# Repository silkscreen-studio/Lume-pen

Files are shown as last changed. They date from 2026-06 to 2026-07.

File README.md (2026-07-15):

# LUME Pen
The most ordinary pen, except that it has electronics stuffed inside, on a flexible PCB. It can even tell the time and double as a pomodoro timer, thanks to a tiny custom 7 segment display, with a capacitive slider to control it easily 

I mainly made this project to challenge myself on integrating electronics in such a tight space (6mm hollow tube) and to design my first Flex PCB. Also, I always thought that integrating a mini segmented display and a capacitive slider into a pen body would look really cool, and it looks exactly as cool as I imagined it. 

With this clock and pomodoro timer included in the tool everyone uses when working or studying, no need for distracting apps and constant checks on a phone!

<br><br>
LUME Pen ZINE V1 1

The Lume Pen body is split in 3 parts, in MJF Nylon and SLA clear resin, to make assembly possible while giving texture to the design.
The flex PCB, made of multiple flaps bent over each other to achieve the 5mm width runs all along the pen body, while keeping space for an half-long BIC® cartridge as well as a rod shaped 4.5mm wide li-ion battery. The segments on the display are shaped from the 30x 0402 LEDs with 3 layers: a small 3D printed spacer (FDM, .2mm nozzle), a thin diffuser sheet and a custom designed light mask to get sharp segments, made from a  precisely laser cut 100 microns thin steel plate, also known as a stencil...

# Product Key features:
 - The Lume pen can tell the time, be used as a Pomodoro timer (configurable timer with multiple sessions possible, alterning 5-60 min of work with a 5 minute break), and... be used as a normal pen too...
 - Sleek design, MJF Nylon & Clear Resin body to see the electronics
 - Capacitive slider to enable gesture control
 - Stylish Segmented Display Font [^1], made from 30 orange LEDs
 - No ON/OFF switch: capacitive CMD button to shut it down, can last a few months on a single charge when turned off
 - Magnetic charger (with pogopins), to charge it easily (from a USB-A port)

# Technical Key features:
## Lume pen:
 - Built around the power efficient `ATtiny1616` MCU (16kB FLASH, 2kB SRAM)
 - 2x I²C ICs for the RTC (`RX8111`) and capacitive touch management (`AW93105`)
 - Onboard `LP5907` 3.0V LDO with low quiscent current (12µA)
 - 3.7V Li-ion rod shaped battery, 25mAh, and its `BQ25170` charging IC
 - interfaces with the charger thanks to 4 gold plated contacts (pogopins on the charger): VIN, GND, UPDI and a mating detect pin.
 - Charlieplexed 30x 0402 orange LEDs 4 digit 7-segment display
 - Flexible PCB, ENIG, with stiffener: 125x40mm² panel with both the LUME and charger PCB
## Magnetic charger:
 - Smart charger with the $0.25 `CH32V003` MCU (16kB FLASH, 2kB SRAM)
 - Load switch (`TPS2553DRVR-1`) with latch off overcurrent and short circuit protection, MCU FAULT assertion, MCU ENABLE,
 - mating detection to enable/disable charging
 - 5 white LEDs to display charging animation, and 1 RED FAULT LED

# Schematic:
## Lume Pen schematic
LUME_pen_schematic_V1 0

## Charger shematic

LUME_pen_charger_schematic_V1 0

# PCB Layout:
## LUME flexible Panel:
I decided to panelize it with 2 Lume variant, where I have a line pattern silkscreen on one variant, and a full white pour on the other one, on all the visible parts. Not knowing what the yellow coverlay would look like in real life, I could now see which one looks better. Ordering this dual panel is only $6 more expensive ($40.42 for 5 panel, so 10 Lume PCBs) than the single panel ($34.14 for 5 panel, so 5 Lume PCBs). Why not directly choose a white (or black) coverlay? As it adds a $8 fee, it would have been $42.14 for the single panel (5 Lume PCBs).

For $40, I have 10 Lume pen PCBs (5 of each variant), with PI stiffener and ENIG finish.

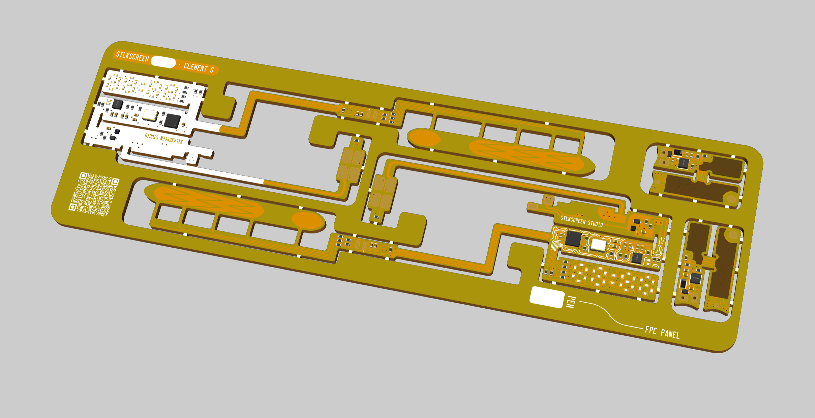
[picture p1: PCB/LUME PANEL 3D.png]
LUME PANEL 3D

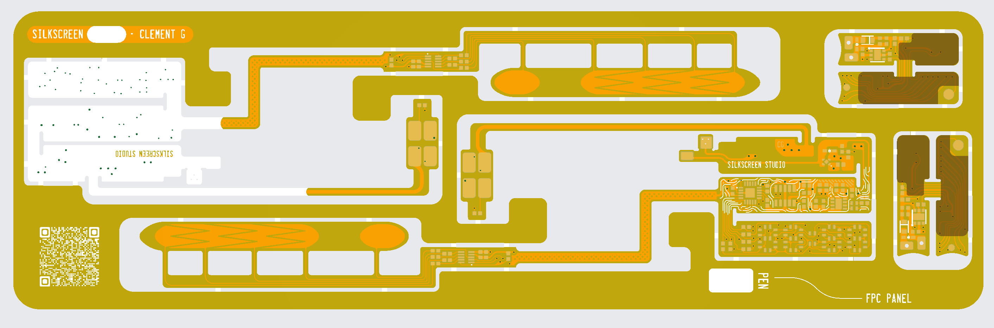
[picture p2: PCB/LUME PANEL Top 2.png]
LUME PANEL Top 2

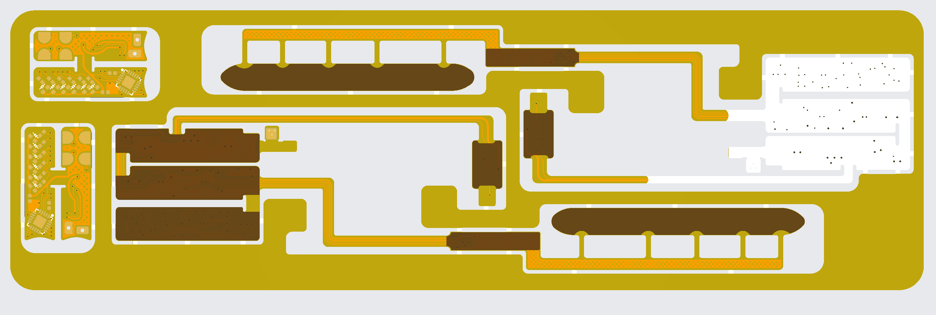
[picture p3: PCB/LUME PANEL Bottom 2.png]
LUME PANEL Bottom 2


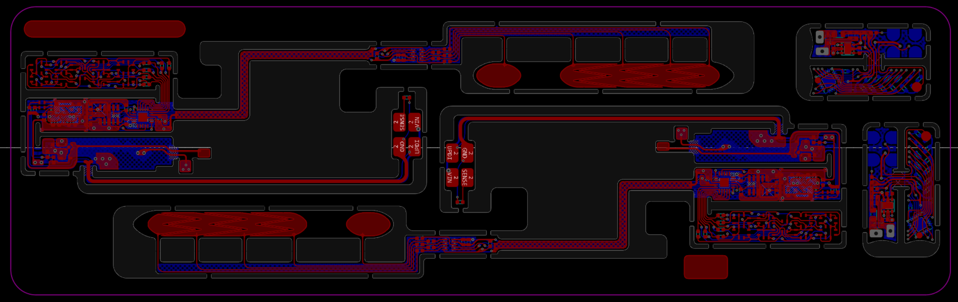
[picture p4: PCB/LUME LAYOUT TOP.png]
LUME LAYOUT PANEL TOP

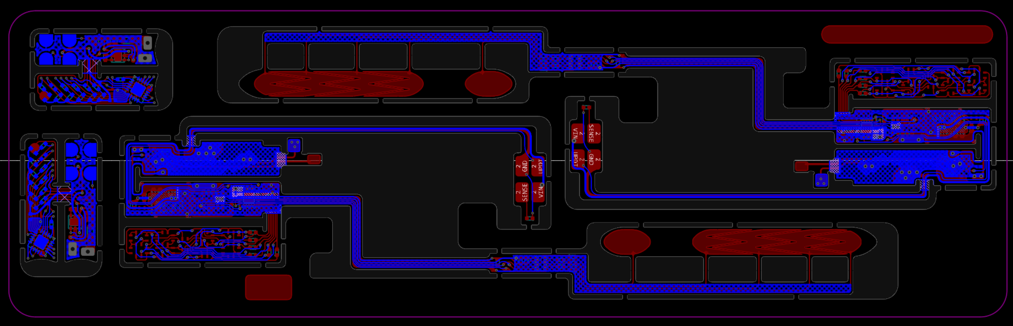
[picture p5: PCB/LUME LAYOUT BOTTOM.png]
LUME LAYOUT PANEL BOTTOM


## Debug friendly FR4 board

Before ordering the flexible PCB, I'll validate the schematic and test the firmware with a Debug-friendly board, on a cheap FR4 board. With its many test points, separated block design allowing easy cut traces and bodge wires, debugging selection switches and UART communication will make the debugging process a lot easier:

Debug friendly FR4 3D

Debug friendly FR4 3D back
Debug friendly FR4 layout

I'm using my dual UPDI programmer and Serial communication debug tool I made for AngstromIO [^2], which explains the specific 'daugther board' footprint, but any UPDI programmer and USB to UART would work perfectly too.

# Firmware:
## Lume pen firmware (ATtiny1616): 
The ATtiny1616 is programmed with the Arduino IDE. I'm using 2 custom made libraries as I needed a lightweight library for the RX8111 (only implementing the clock feature) and a library for the poorly documented AW93105 IC. I used the help of Claude AI to code 2 really basic libraries, especially for the AW93105, and I'll then later built from that a usable library with all the features implemented once I've tried this basis on the Debug-friendly PCB. So I kept these first library as simple as possible to make debugging easier, and this is why the sliding and other gesture aren't implemented yet, so the main MCU code is thus just a sketch, that won't behave properly out of the box (since it can't react to non implemented gesture). The Charlieplexed display and other logic should be working independently though.
The code (thus still a W.I.P) is available in /Firmware/LUME_PEN

## Charger firmware (CH32V003):
The CH32V003 is programmed with the Mounriver Studio IDE. The code (untested for now), that handles power management, Fault handling, LED animation (PWM), and mating detection is available in /Firmware/CHARGER/main.c

<br><br>
# Design Renders
<br><br>
Render 1
Render 2
Render 3
Render 4
Render 10
<br><br>
## ... and under the shell:

Render 5
Render 6
Render 7
Render 8
Render 9

## finally, the magnetic charger:

Rd2

Rd3

# BOM:

| Product | Qty | Part | Value | LCSC Part number | Price/unit | minimum Price [MOQ] | Extended description | Link | Price for 2 pens 1 debug boards & 2 chargers combined |
| --- | --- | --- | --- | --- | --- | --- | --- | ---  | --- |
| LUME PEN | 1 | ATTINY1616-MNR |  | C507118 | $1.09 | $1.09 | Main MCU | https://www.lcsc.com/product-detail/C507118.html | $3.29 |
| LUME PEN | 1 | TI LP5907SNX-3.0/NOPB | 3.0V | C182423 | $0.1967 | $0.98 [5] | LDO | https://www.lcsc.com/product-detail/C182423.html | $0.98 |
| LUME PEN | 1 | BQ25170DSGR |  | C5208201 | $0.59 | $0.59 | Li ion battery charger IC | https://www.lcsc.com/product-detail/C5208201.html | $1.77 |
| LUME PEN | 1 | EPSON RX8111CE-B |  | C2929261 | $1.1739 | $1.1739 | RTC | https://www.lcsc.com/product-detail/C2929261.html | $3.52 |
| LUME PEN | 1 | AW93105DNR |  | C5241002 | $0.5438 | $0.5438 | Capacitive touch IC (5 channels) | https://www.lcsc.com/product-detail/C5241002.html | $1.63 |
| LUME PEN | 1 | LESD5D5.0CT1G |  | C5199850 | $0.0166 | $0.83 [50] | TVS diode | https://www.lcsc.com/product-detail/C5199850.html | $0.83 |
| LUME PEN | 30 | XL-1005UOC | Vf: 2.0V | C965791 | $0.0142 | $0.71 [50] | 0402 Orange LED (display) | https://www.lcsc.com/product-detail/C965791.html | $1.42 |
| LUME PEN | 31 | XL-1005SURC | Vf: 2.0V | C25503345 | $0.0083 | $0.42 [50] | 0402 Red LED (display (alternate color) and /PG charging) | https://www.lcsc.com/product-detail/C25503345.html | $0.42 |
| LUME PEN | 5 | CL05A104KA5NNNC | 100nF | C100072 | $0.0063 | $0.63 [100] | 0402 MLCC | https://www.lcsc.com/product-detail/C100072.html | $0.63 |
| LUME PEN | 3 | CL05A105KO5NNNC | 1µF | C29266 | $0.0102 | $1.02 [100] | 0402 MLCC | https://www.lcsc.com/product-detail/C29266.html | $1.02 |
| LUME PEN | 2 | GRM155R61E475ME15D | 4.7µF | C2858031 | $0.15 | $1.51 [10] | 0402 MLCC | https://www.lcsc.com/product-detail/C2858031.html | $1.51 |
| LUME PEN | 1 | XL-1005UBC | Vf: 3.0V | C22355736 | $0.008 | $0.40 [50] | 0402 Blue LED (STAT Charging) | https://www.lcsc.com/product-detail/C22355736.html | $0.40 |
| LUME PEN | 2 | CRCW04024K70FKED | 4.7k | C482193 | $0.0037 | $0.37 [100] | 0402 Resistor | https://www.lcsc.com/product-detail/C482193.html | $0.37 |
| LUME PEN | 3 | CRCW040220K0FKED | 20k | C482096 | $0.0043 | $0.43 [100] | 0402 Resistor | https://www.lcsc.com/product-detail/C482096.html | $0.43 |
| LUME PEN | 1 | CRCW040224K0FKED | 24k | C295000 | $0.0042 | $0.42 [100] | 0402 Resistor | https://www.lcsc.com/product-detail/C295000.html | $0.42 |
| LUME PEN | 1 | CRCW040227K0FKEDC | 27k | C1730799 | $0.0052 | $0.52 [100] | 0402 Resistor | https://www.lcsc.com/product-detail/C1730799.html | $0.52 |
| LUME PEN | 3 | CRCW040210K0JNED | 10k | C191984 | $0.0035 | $0.35 [100] | 0402 Resistor | https://www.lcsc.com/product-detail/C191984.html | $0.35 |
| LUME PEN | 1 | CRCW0402100KFKEDC | 100k | C844712 | $0.0063 | $0.63 [100] | 0402 Resistor | https://www.lcsc.com/product-detail/C844712.html | $0.63 |
| LUME PEN | 1 | CRCW0402200KFKED | 200k | C482093 | $0.0046 | $0.46 [100] | 0402 Resistor | https://www.lcsc.com/product-detail/C482093.html | $0.46 |
| LUME PEN | 6 | CRCW0402680RFKED | 680 | C482224 | $0.0047 | $0.47 [100] | 0402 Resistor | https://www.lcsc.com/product-detail/C482224.html | $0.47 |
| LUME PEN | 5 | CRCW04020000Z0ED | 0 | C190119 | $0.0043 | $0.43 [100] | 0402 shunt Resistor (capacitive tuning; other values needed for tuning) | https://www.lcsc.com/product-detail/C190119.html | $0.43 |
|  |  |  |  |  |  |  |  |  |  |
| CHARGER | 5 | XL-1005UWC | Vf: 2.8V | C20613596 | $0.0112 | $0.56 [50] | 0402 White LED | https://www.lcsc.com/product-detail/C20613596.html | $0.56 |
| CHARGER | 1 | XL-1005SURC | Vf: 2.0V | C25503345 | $0.0083 | $0.42 [50] | 0402 Red LED | https://www.lcsc.com/product-detail/C25503345.html | / |
| CHARGER | 2 | CRCW040220K0FKED | 20k | C482096 | $0.0043 | $0.43 [100] | 0402 Resistor | https://www.lcsc.com/product-detail/C482096.html | / |
| CHARGER | 1 | CRCW0402100KFKEDC | 100k | C844712 | $0.0063 | $0.63 [100] | 0402 Resistor | https://www.lcsc.com/product-detail/C844712.html | / |
| CHARGER | 1 | CRCW040210K0JNED | 10k | C191984 | $0.0035 | $0.35 [100] | 0402 Resistor | https://www.lcsc.com/product-detail/C191984.html | / |
| CHARGER | 3 | CL05A104KA5NNNC | 100nF | C100072 | $0.0063 | $0.63 [100] | 0402 MLCC | https://www.lcsc.com/product-detail/C100072.html | / |
| CHARGER | 6 | CRCW0402330RFKED | 330 | C71626 | $0.0042 | $0.42 [100] | 0402 Resistor | https://www.lcsc.com/product-detail/C71626.html | $0.42 |
| CHARGER | 1 | CL05A106MP8NUB8 | 10µF | C307415 | $0.15 | $0.73 [5] | 0402 MLCC | https://www.lcsc.com/product-detail/C307415.html | $0.73 |
| CHARGER | 1 | TPS2553DRVR-1 |  | C411878 | $0.39 | $1.94 [5] | Load switch IC | https://www.lcsc.com/product-detail/C411878.html | $1.94 |
| CHARGER | 1 | CH32V003F4U6 |  | C5299908 | $0.32 | $1.58 [5] | Main MCU | https://www.lcsc.com/product-detail/C5299908.html | $1.58 |
| CHARGER | 1 | LESD5D5.0CT1G |  | C5199850 | $0.0168 | $0.84 [50] | TVS diode | https://www.lcsc.com/product-detail/C5199850.html | / |
| CHARGER | 1 | RB520SM-40T2R |  | C253514 | $0.03 | $0.56 [20] | Schottky diode | https://www.lcsc.com/product-detail/C253514.html | $0.56 |
| CHARGER | 4 | BWCD-L4.5W2.0H2.3 |  | C2826546 | $0.07 | $0.36 [5] | Pogopin | https://www.lcsc.com/product-detail/C2826546.html | $0.72 |
| CHARGER | 1 | section of USB cable |  |  |  |  | can be any USB cable; that got the ends stripped |  | / |
|  |  |  |  |  |  |  |  |  |  |
| ADDITIONAL PARTS (DEBUG PCB) | 1 | LESD5D5.0CT1G |  | C5199850 | $0.0166 | $0.83 [50] | TVS diode | https://www.lcsc.com/product-detail/C5199850.html | / |
| ADDITIONAL PARTS (DEBUG PCB) | 1 | RB520SM-40T2R |  | C253514 | $0.03 | $0.56 [20] | Schottky diode | https://www.lcsc.com/product-detail/C253514.html | / |
| ADDITIONAL PARTS (DEBUG PCB) | 2 | MK-12C02-G015 |  | C2911519 | $0.014 | $0.67 [5] | Slide Switch SPDT | https://www.lcsc.com/product-detail/C2911519.html | $0.67 |
| ADDITIONAL PARTS (DEBUG PCB) | 2 | HC-PM254-8.5H-1x3PW-02A |  | C22373927 | $0.09 | $0.46 [5] | 90° 2.54mm 1x3 HEADERS | https://www.lcsc.com/product-detail/C22373927.html | $0.46 |
| ADDITIONAL PARTS (DEBUG PCB) | 5 | FR4 Debug PCB |  |  | $2.00 | $2.00 |  | https://jlcpcb.com | $2.00 |
| ADDITIONAL PARTS (CHARGER) |  | Epoxy |  |  |  |  | mixed with white acrilyc paint (light diffusing) |  | - |
|  |  |  |  |  |  |  |  |  |  |
| GENERAL | 5 | Flex PCB PANEL |  |  | $41.42 | $41.42 |  | https://jlcpcb.com | $41.42 |
| GENERAL | - | 3D printed parts |  |  | $4.87 | $4.87 | see 3D-CAD/3D-Printed-PARTS | https://jlc3dp.com | $9.74 |
| GENERAL | 1 | Stencil |  |  | $3.07 | $3.07 |  | https://jlcpcb.com | $3.07
| GENERAL | 2 | neodymium magnets 5x5x5mm (cube) 10pcs |  |  |  | $4.53 | ($2.54 + $1.99 shipping) | https://fr.aliexpress.com/item/1005011587371110.html | $4.53 |
|  |  |  |  |  |  |  |  |  |  |
|  |  |  |  |  |  |  |  |  |  |
| SHIPPING (first order FR4 debug only + stencil) |  | JLCPCB |  |  | $1.50 x 2 |  |  |  | $3.00 |
| SHIPPING (second order FPC + 3D prints) |  | JLCPCB & 3DP |  |  | $1.50 |  |  |  | $1.50 |
| SHIPPING (first order: components) |  | LCSC (GDSL) |  |  | $10.20 |  |  |  | $10.20 |
|  |  |  |  |  |  |  |  |  |  |
| TOTAL (first order debug only) |  |  |  |  |  |  |  |  | $47.53 |
| TOTAL (second order FPC + 3D prints) |  |  |  |  |  |  |  |  | $52.66 |
|  |  |  |  |  |  |  |  |  |  |
| PROJECT GRAND TOTAL |  |  |  |  |  |  |  |  | $104.72 |

[^1]: Inspired from the **Seamless** font, a design by Michiel de Boer (_Pozy_): https://www.youtube.com/watch?v=RTB5XhjbgZA&t=6s and https://www.michieldb.nl/other/segments/
[^2]: more info on my other repository: https://github.com/Dieu-de-l-elec/AngstromIO-devboard

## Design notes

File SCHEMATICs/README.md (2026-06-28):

# SVG schematics:
Lume pen and charger schematics, as well as the debug friendly PCB, which is just both the Lume and charger schematic in one schematic, with a few additional switches and passives.

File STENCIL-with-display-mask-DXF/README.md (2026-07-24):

To get the stencil for soldering the FPC and detach the Display light mask coupon, the stencil can be ordered from JLCPCB with the GERBER file provided here. There is also a .dxf file just in case.

This stencil has all the pads aperture for the FPC, as well as 5 detachable coupons, 100 microns thin steel plate that shapes the segments from the LEDs on the display. The coupons should detach easily by cutting the tabs with a cutter.

JLCPCB order: select 0.1mm thickness, custom size 100x100. Should be $3 (unless additionnal fees for the irregular shape, we'll see how it turns out).

The stencil coupon is also available in STEP.

Stencil

# And in real life: 
Wow! the coupons just arrived and I'm genuinely amazed by the quality, precision, etc. It turned out exactly like I wanted: shiny, quite stiff, the perfect segment shaper with the neat LUME text cut on the side. 






it took me 2 coupons to get the right cutting move, and the clue is just patience and many careful passes with a utility knife on both sides. it'll fall right off after a few cuts. just don't be in too much of a hurry as a sudden move could snap the coupon right off and bend it in the process.



This thing is genuinely small (5x22mm), and while they look huge on the picture, look at the size comparison with a grain of rice & a 1x1mm IC package (the LDO btw):




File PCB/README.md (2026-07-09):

## To order the flex PCB on JLCPCB:

_Different designs: 3 designs (panel by customer)_

_EDA software: EasyEDA Pro_

_Stiffener: based on EasyEDA stiffener layer_

_coverlay: Yellow_

_& other parameters as default_

Should be $40.42

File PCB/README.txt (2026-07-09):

To order the flex PCB on JLCPCB:
Different designs: 3 designs (panel by customer)
EDA software: EasyEDA Pro
Stiffener: based on EasyEDA stiffener layer
coverlay: Yellow
& other parameters as default

Should be $40.42

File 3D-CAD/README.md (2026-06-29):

All the 3D printed parts can be found in a subfolder, the DXF file is for the diffuser sheet, that can be laser cut out of a diffusing material (I'll try with tracing paper, it usually gives decent results), and the whole assembly (STEP) and design files (F3Z) can be found here too.

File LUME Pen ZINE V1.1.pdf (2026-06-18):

# LUME

## The time in the Palm of your hand

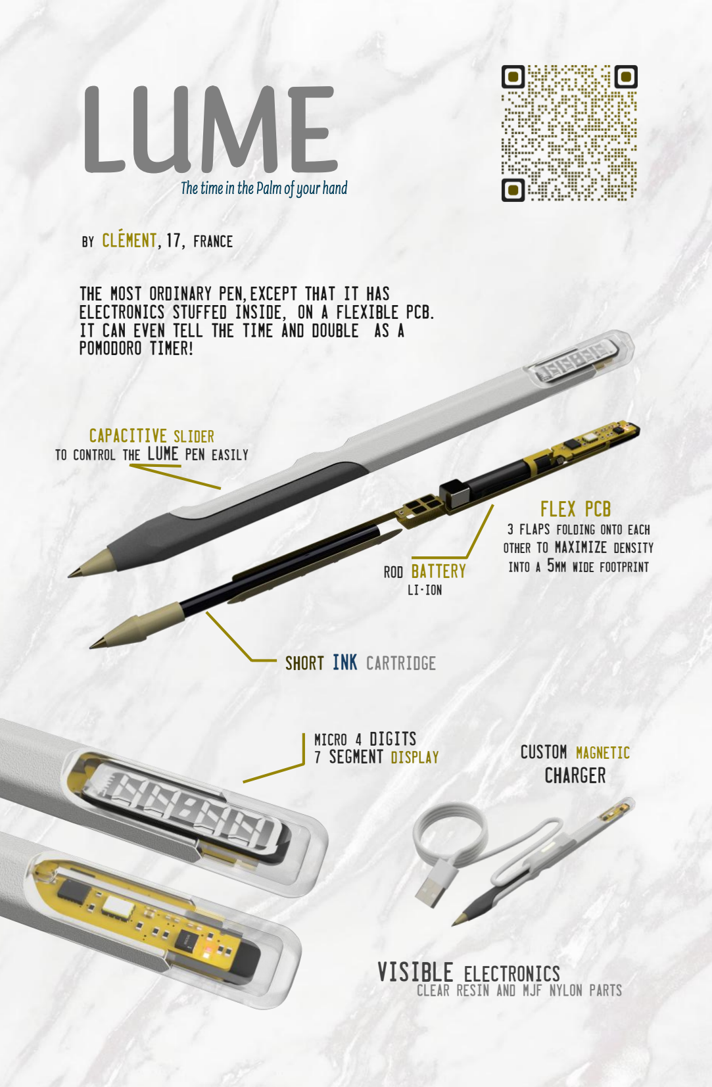
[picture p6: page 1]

Micro 4 digits
7 segment display

Visible electronics
Clear resin and MJF Nylon Parts

Custom magnetic
charger

Rod battery
Li-ion

Short Ink cartridge

Flex PCB

3 flaps folding onto each
other to maximize density
into a 5mm wide footprint

Capacitive slider
To control the Lume pen easily

The most ordinary pen, except that it has electronics stuffed inside, on a flexible PCB. It can even tell the time and double as a pomodoro timer!

By Clement, 17, France

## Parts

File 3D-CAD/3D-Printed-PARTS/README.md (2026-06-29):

# 3D printed parts

The Lume body is made of 3 Parts that can be printed via JLC 3DP services. 2 MJF Nylon parts, and one clear resin part.
The charger cover can be printed in Nylon too, to get a premium surface finish, while a few other parts, more functionnal than aesthetic, could be 3D printed with a .2mm nozzle (FDM).

The 3 pen body parts would then be glued together once the pen is fully assembled, and for the charger, resin will be poured around the FPC inside the charger cover, with on top the charger plate, to provide support for the pogopins, while also creating a diffusing window for the 6 LEDs. 

| \ | Main 3DP part - middle body | clear tip | Ink cardridge tip | display spacer | Charger cover | Charger plate |
| :---: | :---: | :---: | :---: | :---: | :---: | :---: |
| **Part name** | P1 | P2 | P3 | P4 | P5 | P6 |
| **Preview** | P1 | P2 | P3 | P4 | P5 | P6 |
| **Material** | MJF PA12S-HP Nylon | SLA 8001 resin  | MJF PA12S-HP Nylon | PLA, FDM, .2mm nozzle | MJF PA12S-HP Nylon | PLA, FDM, .2mm nozzle |
| **Color** | grayish-white  | transparent (oil sprayed) | dyied black | black | grayish-white | white |
| **Service** | JLC3DP | JLC3DP | JLC3DP | `at home` | JLC3DP | `at home` |
| **Price** | $0.94 | $1.95 | $1.04 | `-` | $0.94 | `-` |

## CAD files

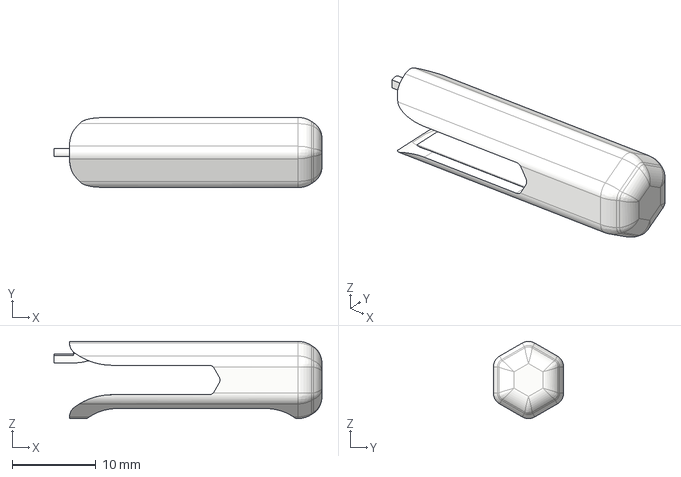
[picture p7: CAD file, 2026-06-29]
3D-CAD/3D-Printed-PARTS/LUME PEN CAD 3D prints P2.step
32.0 x 8.40 x 9.23 mm

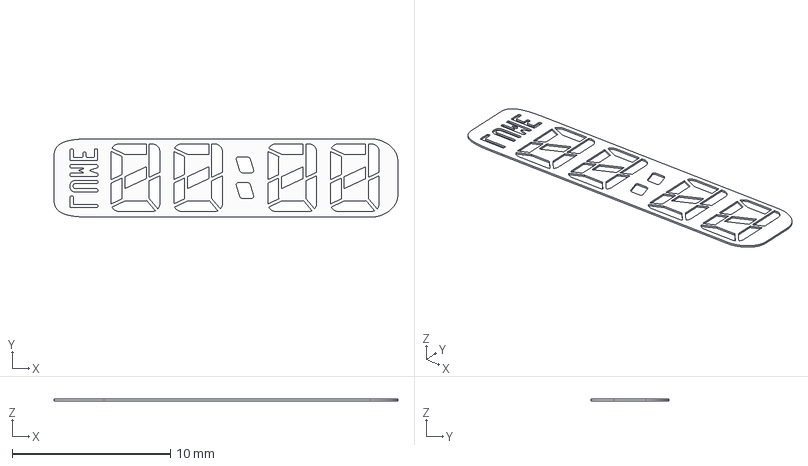
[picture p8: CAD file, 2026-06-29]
STENCIL-with-display-mask-DXF/LUME PEN CAD Stencil 3D.step
21.7 x 4.96 x 0.1 mm

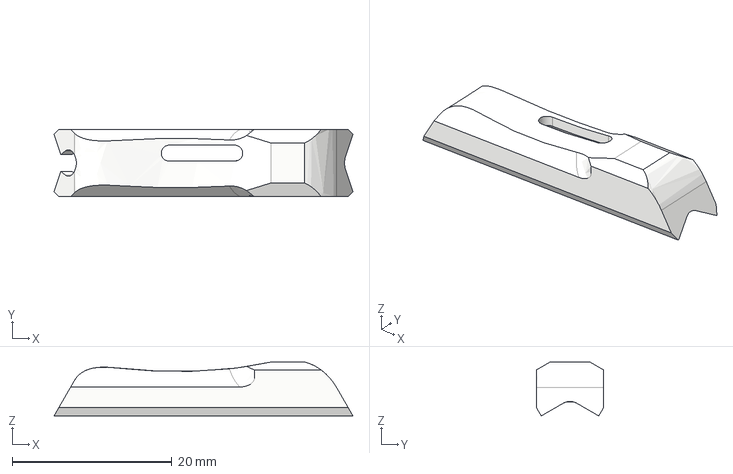
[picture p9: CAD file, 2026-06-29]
3D-CAD/3D-Printed-PARTS/LUME PEN Charger CAD 3D prints P5.step
37.4 x 8.40 x 6.74 mm

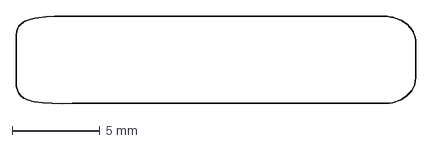
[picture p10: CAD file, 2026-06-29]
3D-CAD/Diffuser sheet DXF - for laser cutting .dxf
22.7 x 5.00 mm

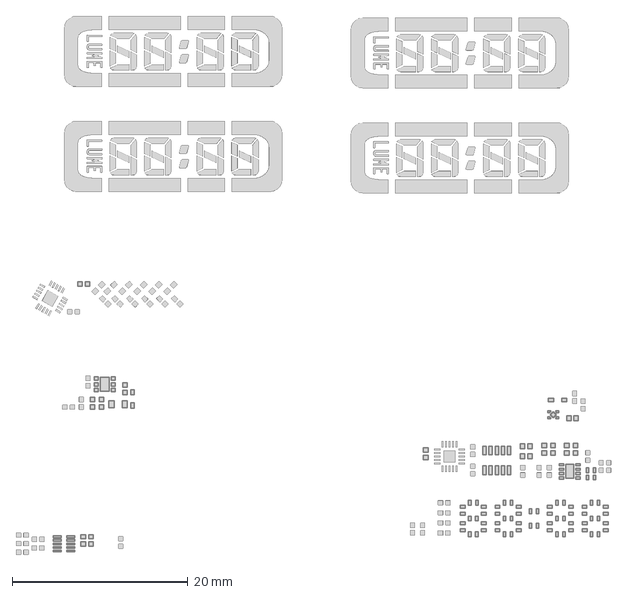
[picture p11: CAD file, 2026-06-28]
STENCIL-with-display-mask-DXF/DXF Stencil with light mask PCB_2026-06-28_AutoCAD2007.dxf
67.7 x 61.3 mm

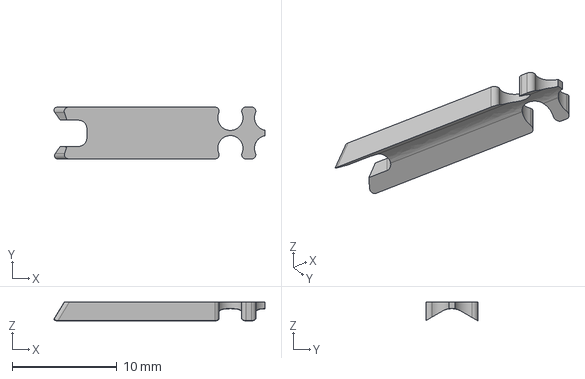
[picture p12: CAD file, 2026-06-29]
3D-CAD/3D-Printed-PARTS/LUME PEN Charger CAD 3D prints P6.step
20.1 x 4.95 x 1.79 mm

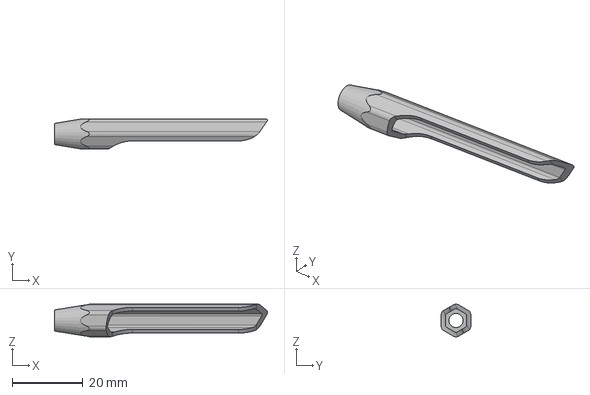
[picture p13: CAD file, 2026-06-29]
3D-CAD/3D-Printed-PARTS/LUME PEN CAD 3D prints P3.step
60.2 x 8.40 x 9.24 mm

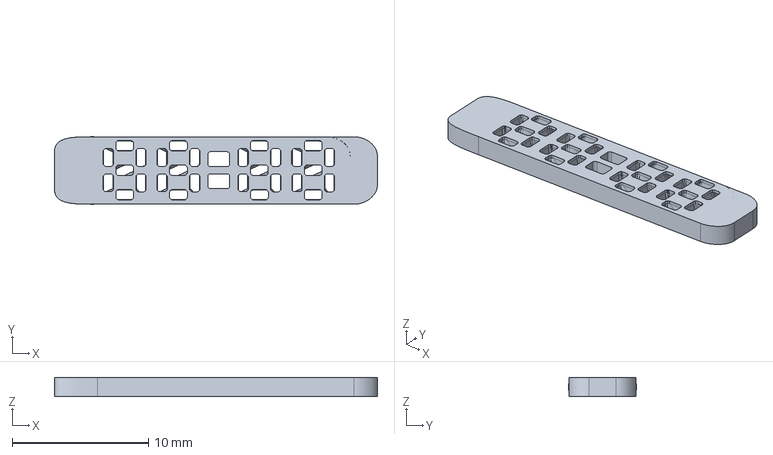
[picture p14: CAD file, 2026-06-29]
3D-CAD/3D-Printed-PARTS/LUME PEN CAD 3D prints P4.step
23.7 x 4.96 x 1.40 mm

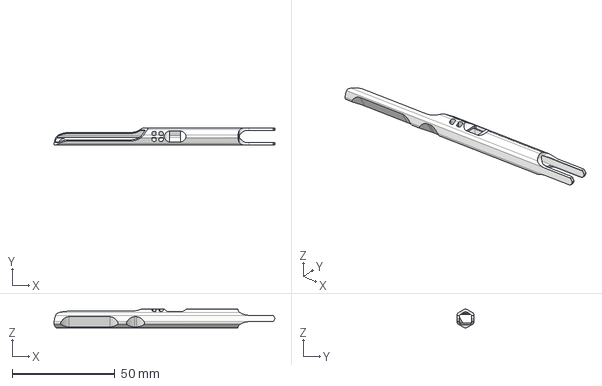
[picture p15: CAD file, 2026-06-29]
3D-CAD/3D-Printed-PARTS/LUME PEN CAD 3D prints P1.step
107.7 x 8.40 x 9.23 mm

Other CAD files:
3D-CAD/LUME PEN CAD whole assembly.step
3D-CAD/LUME PEN CAD design files.f3z

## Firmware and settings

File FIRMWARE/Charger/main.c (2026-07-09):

/*
 *   CH32 magnetic charger code | LUME Pen | by Silkscreen Studio | https://github.com/silkscreen-studio/Lume-pen
 *   6 PWM driven LEDs, pen mating detection, load switch control, fault handling
 *   
 *   After creating a new Mounriver Studio project and selecting the chip 'CH32V003F4U', the following main.c file can be replaced with the following code (in User>main.c)  
 *   as the CH32 doesn't comes with an external oscillator, the file 'system_ch32v00x.c has to be modified, changing the code as below:
 *            //#define SYSCLK_FREQ_8MHz_HSI    8000000
 *            //#define SYSCLK_FREQ_24MHZ_HSI   HSI_VALUE
 *            #define SYSCLK_FREQ_48MHZ_HSI   48000000               // This line has to be uncommented
 *            //#define SYSCLK_FREQ_8MHz_HSE    8000000
 *            //#define SYSCLK_FREQ_24MHz_HSE   HSE_VALUE
 *            //#define SYSCLK_FREQ_48MHz_HSE   48000000              Default line that should be commented
 */

#include "debug.h"

typedef struct {
    GPIO_TypeDef *PORT;
    uint16_t PIN;
} GPIOstruct;

GPIOstruct GPIO_LED[] = {
    {GPIOD, GPIO_Pin_4}, // L0 // RED   T2/CH1
    {GPIOC, GPIO_Pin_0}, // L1    T2/CH3
    {GPIOD, GPIO_Pin_3}, // L2    T2/CH2
    {GPIOD, GPIO_Pin_2}, // L3    T1/CH1
    {GPIOC, GPIO_Pin_4}, // L4    T1/CH4
    {GPIOC, GPIO_Pin_3}, // L5    T1/CH3
};

GPIOstruct GPIO_SENSE = {GPIOD, GPIO_Pin_6};
GPIOstruct GPIO_NFAULT = {GPIOD, GPIO_Pin_0};
GPIOstruct GPIO_5V_POGO_EN = {GPIOA, GPIO_Pin_2};

const uint32_t FREQPWM = 200000;

uint16_t PRSC = 0;
uint16_t ARR = 0;

void GPIO_config() {
    RCC_APB2PeriphClockCmd (RCC_APB2Periph_GPIOA | RCC_APB2Periph_GPIOC | RCC_APB2Periph_GPIOD, ENABLE);

    RCC_APB1PeriphClockCmd (RCC_APB1Periph_TIM2, ENABLE);  // PWM
    RCC_APB2PeriphClockCmd (RCC_APB2Periph_TIM1, ENABLE);  // PWM
    RCC_APB2PeriphClockCmd (RCC_APB2Periph_ADC1, ENABLE);  // ADC
    RCC_ADCCLKConfig (RCC_PCLK2_Div8);

    GPIO_InitTypeDef GPIO_InitStructure = {0};

    for (uint8_t LED = 0; LED < 6; LED++) {
        GPIO_InitStructure.GPIO_Pin = GPIO_LED[LED].PIN;
        GPIO_InitStructure.GPIO_Mode = GPIO_Mode_AF_PP;
        GPIO_InitStructure.GPIO_Speed = GPIO_Speed_30MHz;
        GPIO_Init (GPIO_LED[LED].PORT, &GPIO_InitStructure);
    }

    GPIO_InitStructure.GPIO_Pin = GPIO_SENSE.PIN;
    GPIO_InitStructure.GPIO_Mode = GPIO_Mode_AIN;
    GPIO_InitStructure.GPIO_Speed = GPIO_Speed_30MHz;
    GPIO_Init (GPIO_SENSE.PORT, &GPIO_InitStructure);

    GPIO_InitStructure.GPIO_Pin = GPIO_NFAULT.PIN;
    GPIO_InitStructure.GPIO_Mode = GPIO_Mode_IPU;
    GPIO_InitStructure.GPIO_Speed = GPIO_Speed_30MHz;
    GPIO_Init (GPIO_NFAULT.PORT, &GPIO_InitStructure);

    GPIO_InitStructure.GPIO_Pin = GPIO_5V_POGO_EN.PIN;
    GPIO_InitStructure.GPIO_Mode = GPIO_Mode_Out_PP;
    GPIO_InitStructure.GPIO_Speed = GPIO_Speed_30MHz;
    GPIO_Init (GPIO_5V_POGO_EN.PORT, &GPIO_InitStructure);

    ADC_InitTypeDef ADC_InitStructure = {0};
    ADC_DeInit (ADC1);
    ADC_InitStructure.ADC_Mode = ADC_Mode_Independent;
    ADC_InitStructure.ADC_ScanConvMode = DISABLE;
    ADC_InitStructure.ADC_ContinuousConvMode = ENABLE;
    ADC_InitStructure.ADC_ExternalTrigConv = ADC_ExternalTrigConv_None;
    ADC_InitStructure.ADC_DataAlign = ADC_DataAlign_Right;
    ADC_InitStructure.ADC_NbrOfChannel = 1;
    ADC_Init (ADC1, &ADC_InitStructure);

    ADC_RegularChannelConfig (ADC1, ADC_Channel_6, 1, ADC_SampleTime_241Cycles);

    ADC_Cmd (ADC1, ENABLE);
    ADC_ResetCalibration (ADC1);
    while (ADC_GetResetCalibrationStatus (ADC1));
    ADC_StartCalibration (ADC1);
    while (ADC_GetCalibrationStatus (ADC1));

    ADC_SoftwareStartConvCmd (ADC1, ENABLE);

    uint32_t timer_clk = SystemCoreClock;  // 48MHz

    PRSC = (timer_clk / (FREQPWM * 65536)) + 1;
    ARR = (timer_clk / ((PRSC + 1) * FREQPWM)) - 1;

    TIM_Cmd (TIM2, DISABLE);
    TIM_OCInitTypeDef TIM_OCInitStructure = {0};
    TIM_TimeBaseInitTypeDef TIM_TimeBaseInitStructure = {0};

    TIM_TimeBaseInitStructure.TIM_Period = ARR;
    TIM_TimeBaseInitStructure.TIM_Prescaler = PRSC;
    TIM_TimeBaseInitStructure.TIM_ClockDivision = TIM_CKD_DIV1;
    TIM_TimeBaseInitStructure.TIM_CounterMode = TIM_CounterMode_Up;
    TIM_TimeBaseInit (TIM2, &TIM_TimeBaseInitStructure);

    TIM_OCInitStructure.TIM_OCMode = TIM_OCMode_PWM1;
    TIM_OCInitStructure.TIM_OutputState = TIM_OutputState_Enable;
    TIM_OCInitStructure.TIM_Pulse = 0;
    TIM_OCInitStructure.TIM_OCPolarity = TIM_OCPolarity_High;


    TIM_OC1Init (TIM2, &TIM_OCInitStructure);
    TIM_OC3Init (TIM2, &TIM_OCInitStructure);
    TIM_OC2Init (TIM2, &TIM_OCInitStructure);
    TIM_CtrlPWMOutputs (TIM2, ENABLE);

    TIM_OC2PreloadConfig (TIM2, TIM_OCPreload_Enable);
    TIM_OC3PreloadConfig (TIM2, TIM_OCPreload_Enable);
    TIM_OC1PreloadConfig (TIM2, TIM_OCPreload_Enable);
    TIM_ARRPreloadConfig (TIM2, ENABLE);
    TIM_Cmd (TIM2, ENABLE);


    TIM_Cmd (TIM1, DISABLE);

    TIM_TimeBaseInitStructure.TIM_Period = ARR;
    TIM_TimeBaseInitStructure.TIM_Prescaler = PRSC;
    TIM_TimeBaseInitStructure.TIM_ClockDivision = TIM_CKD_DIV1;
    TIM_TimeBaseInitStructure.TIM_CounterMode = TIM_CounterMode_Up;
    TIM_TimeBaseInit (TIM1, &TIM_TimeBaseInitStructure);

    TIM_OCInitStructure.TIM_OCMode = TIM_OCMode_PWM1;
    TIM_OCInitStructure.TIM_OutputState = TIM_OutputState_Enable;
    TIM_OCInitStructure.TIM_Pulse = 0;
    TIM_OCInitStructure.TIM_OCPolarity = TIM_OCPolarity_High;

    TIM_OC1Init (TIM1, &TIM_OCInitStructure);
    TIM_OC4Init (TIM1, &TIM_OCInitStructure);
    TIM_OC3Init (TIM1, &TIM_OCInitStructure);
    TIM_CtrlPWMOutputs (TIM1, ENABLE);

    TIM_OC1PreloadConfig (TIM1, TIM_OCPreload_Enable);
    TIM_OC4PreloadConfig (TIM1, TIM_OCPreload_Enable);
    TIM_OC3PreloadConfig (TIM1, TIM_OCPreload_Enable);

    TIM_ARRPreloadConfig (TIM1, ENABLE);
    TIM_Cmd (TIM1, ENABLE);
}

void analogWritePWM (uint8_t LED, uint16_t duty_cycle) {
    if (LED >= 6) {
        return;
    }
    if (duty_cycle > 1023) {
        duty_cycle = 1023;
    }
    uint16_t _CCR = ((uint32_t)(ARR + 1) * duty_cycle) / 1023;

    switch (LED) {
    case 0: TIM_SetCompare1 (TIM2, _CCR); break;
    case 1: TIM_SetCompare3 (TIM2, _CCR); break;
    case 2: TIM_SetCompare2 (TIM2, _CCR); break;
    case 3: TIM_SetCompare1 (TIM1, _CCR); break;
    case 4: TIM_SetCompare4 (TIM1, _CCR); break;
    case 5: TIM_SetCompare3 (TIM1, _CCR); break;
    }
}

uint8_t FAULT() {
    return !GPIO_ReadInputDataBit (GPIO_NFAULT.PORT, GPIO_NFAULT.PIN);
}

void set_5V_POGO_EN() {
    GPIO_SetBits (GPIO_5V_POGO_EN.PORT, GPIO_5V_POGO_EN.PIN);
}

void remove_5V_POGO_EN() {
    GPIO_ResetBits (GPIO_5V_POGO_EN.PORT, GPIO_5V_POGO_EN.PIN);
}

uint8_t checkLUMEPresence() {
    float vref = 5.0f;
    float sum = 0.0f;
    for (uint8_t i = 0; i < 20; i++) {
        sum += (vref * ADC_GetConversionValue (ADC1)) / 1024.0f;
        Delay_Ms (5);
    }
    float ADC_avgVoltage = sum / 20;
    if (ADC_avgVoltage >= 2.2 && ADC_avgVoltage <= 2.8) {
        return 1;  // should be around 2.5V if the LUME is connected
    } else {
        return 0;
    }
}

void fade_IN_LED (uint8_t LED, uint32_t duration) {
    for (uint32_t rise = 0; rise < 1020; rise += 6) {  // 170
        analogWritePWM (LED, rise);
        Delay_Ms (duration / 170);
    }
}

void fade_OUT_LED (uint8_t LED, uint32_t duration) {
    for (uint32_t fall = 1020; fall > 0; fall -= 6) {  // 170 steps
        analogWritePWM (LED, fall);
        Delay_Ms (duration / 170);
    }
}

void clear_LED() {
    for (uint8_t LED = 0; LED < 6; LED++) {
        analogWritePWM (LED, 0);
    }
}

int main (void) {

    SystemCoreClockUpdate();
    Delay_Init();

    GPIO_config();
    remove_5V_POGO_EN();

    for (uint8_t LED = 1; LED < 6; LED++) {
        fade_IN_LED (LED, 240);
    }
    for (uint8_t LED = 1; LED < 6; LED++) {
        fade_OUT_LED (LED, 240);
    }
    clear_LED();

    while (1) {
        if (checkLUMEPresence()) {
            for (uint8_t it = 0; it < 2; it++) {
                for (uint8_t LED = 1; LED < 6; LED++) {
                    analogWritePWM (LED, 255);
                    Delay_Ms (350);
                    analogWritePWM (LED, 0);
                    Delay_Ms (150);
                }
            }
            if (checkLUMEPresence() && !FAULT()) {  // Enable charging
                set_5V_POGO_EN();
                while (checkLUMEPresence() && !FAULT()) {
                    for (uint8_t LED = 1; LED < 6; LED++) {
                        fade_IN_LED (LED, 100);
                        Delay_Ms (100);
                        fade_OUT_LED (LED, 100);
                        Delay_Ms (500);
                        if (FAULT()) {
                            break;
                        }
                    }
                }
            }
        }

        if (FAULT()) {
            remove_5V_POGO_EN();
            clear_LED();
            fade_IN_LED (0, 200);  // RED LED
            Delay_Ms (2600);
            fade_OUT_LED (0, 200);
            set_5V_POGO_EN();
            fade_IN_LED (0, 200);
            fade_OUT_LED (0, 200);
        }

        if (!FAULT()) {
            fade_IN_LED (1, 250);
            fade_OUT_LED (1, 250);
        }

        Delay_Ms(500);
    }
}

//Pins:

// PD6 Sense analog IN

// PC0 LEDW1 digital PWM OUT
// PD3 LEDW2 digital PWM OUT
// PD2 LEDW3 digital PWM OUT
// PC4 LEDW4 digital PWM OUT
// PC3 LEDW5 digital PWM OUT
// PD4 LED R digital PWM OUT

// PA2 5V Pogo EN digital OUT
// PD0 NFAULT digital IN

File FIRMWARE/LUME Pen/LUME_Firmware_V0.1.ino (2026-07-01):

////////////////////////////////////////////////////////////////////////////////
//                                                                            //
//         Minimal Firmware V1.0  |  LUME pen | Silkscreen Studio             //
//                                                                            //
//     Not all the logic is implemented yet, it's just a rough basis.         //
//   managing touch events with the AW93105 will be implemented later on,     //
// once I have the 'debug-friendly board' to test and complete the libraries  //
//                                                                            //
////////////////////////////////////////////////////////////////////////////////


#include <Wire.h>
#include "RTC_LUME.h"
#include "AW9310X_min.h"
#include <avr/sleep.h>

#define AW_NINT PIN_PB2

void touchInterrupt (void) {
}

bool stateTouch [5] = {0, 0, 0, 0, 0};
bool prevStateTouch [5] = {0, 0, 0, 0, 0};

const uint8_t FrameDELAY = 5;

uint8_t brightness = 255;

bool pomodoro = 0;
RTCTime PomTimer;
RTCTime PomStart;
uint8_t N = 1;

uint8_t touchEvent = 0; // when there is a new Touch event
// can be swipe R -> L [1], swipe L -> R then swipe R -> L [2], double tap CMD button [3]
//       Hold CMD button for > 5 sec [4], swipe L -> R [6], single tap R [7], single tap L [8], etc.

uint8_t displayStateMap [6] = {
  0b000000,
  0b000000,
  0b000000,
  0b000000,
  0b000000,
  0b000000
};


const uint8_t digitsStateMap [4][10][6] PROGMEM = {
  {
    { //digit 1 (far left), number 0
      0b000000,
      0b100000,
      0b100000,
      0b100000,
      0b010000,
      0b110000
    },
    { //digit 1 (far left), number 1
      0b000000,
      0b000000,
      0b000000,
      0b000000,
      0b010000,
      0b010000
    },
    { //digit 1 (far left), number 2
      0b000000,
      0b100000,
      0b000000,
      0b100000,
      0b110000,
      0b100000
    },
    { //digit 1 (far left), number 3
      0b000000,
      0b100000,
      0b000000,
      0b000000,
      0b110000,
      0b110000
    },
    { //digit 1 (far left), number 4
      0b000000,
      0b000000,
      0b100000,
      0b000000,
      0b110000,
      0b010000
    },
    { //digit 1 (far left), number 5
      0b000000,
      0b100000,
      0b100000,
      0b000000,
      0b100000,
      0b110000
    },
    { //digit 1 (far left), number 6
      0b000000,
      0b100000,
      0b100000,
      0b100000,
      0b100000,
      0b110000
    },
    { //digit 1 (far left), number 7
      0b000000,
      0b100000,
      0b000000,
      0b000000,
      0b010000,
      0b010000
    },
    { //digit 1 (far left), number 8
      0b000000,
      0b100000,
      0b100000,
      0b100000,
      0b110000,
      0b110000
    },
    { //digit 1 (far left), number 9
      0b000000,
      0b100000,
      0b100000,
      0b000000,
      0b110000,
      0b110000
    }
  },

  {
    { //digit 2 (middle left), number 0
      0b011000,
      0b001000,
      0b010000,
      0b000000,
      0b001000,
      0b001000
    },
    { //digit 2 (middle left), number 1
      0b011000,
      0b000000,
      0b000000,
      0b000000,
      0b000000,
      0b000000
    },
    { //digit 2 (middle left), number 2
      0b010000,
      0b001000,
      0b010000,
      0b001000,
      0b000000,
      0b001000
    },
    { //digit 2 (middle left), number 3
      0b011000,
      0b001000,
      0b010000,
      0b001000,
      0b000000,
      0b000000
    },
    { //digit 2 (middle left), number 4
      0b011000,
      0b000000,
      0b000000,
      0b001000,
      0b001000,
      0b000000
    },
    { //digit 2 (middle left), number 5
      0b001000,
      0b001000,
      0b010000,
      0b001000,
      0b001000,
      0b000000
    },
    { //digit 2 (middle left), number 6
      0b001000,
      0b001000,
      0b010000,
      0b001000,
      0b001000,
      0b001000
    },
    { //digit 2 (middle left), number 7
      0b011000,
      0b000000,
      0b010000,
      0b000000,
      0b000000,
      0b000000
    },
    { //digit 2 (middle left), number 8
      0b011000,
      0b001000,
      0b010000,
      0b001000,
      0b001000,
      0b001000
    },
    { //digit 2 (middle left), number 9
      0b011000,
      0b001000,
      0b010000,
      0b001000,
      0b001000,
      0b000000
    }
  },

  {
    { //digit 3 (middle right), number 0
      0b000100,
      0b000100,
      0b000010,
      0b000010,
      0b000100,
      0b000010
    },
    { //digit 3 (middle right), number 1
      0b000000,
      0b000100,
      0b000010,
      0b000000,
      0b000000,
      0b000000
    },
    { //digit 3 (middle right), number 2
      0b000000,
      0b000100,
      0b000100,
      0b000010,
      0b000100,
      0b000010
    },
    { //digit 3 (middle right), number 3
      0b000000,
      0b000100,
      0b000110,
      0b000010,
      0b000000,
      0b000010
    },
    { //digit 3 (middle right), number 4
      0b000000,
      0b000100,
      0b000110,
      0b000000,
      0b000100,
      0b000000
    },
    { //digit 3 (middle right), number 5
      0b000000,
      0b000100,
      0b000100,
      0b000010,
      0b000100,
      0b000010
    },
    { //digit 3 (middle right), number 6
      0b000100,
      0b000100,
      0b000100,
      0b000010,
      0b000100,
      0b000010
    },
    { //digit 3 (middle right), number 7
      0b000000,
      0b000100,
      0b000010,
      0b000010,
      0b000000,
      0b000000
    },
    { //digit 3 (middle right), number 8
      0b000100,
      0b000100,
      0b000110,
      0b000010,
      0b000100,
      0b000010
    },
    { //digit 3 (middle right), number 9
      0b000000,
      0b000100,
      0b000110,
      0b000010,
      0b000100,
      0b000010
    }
  },
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

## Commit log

2026-06-29 added F3Z design files via LFS
    [LUME PEN CAD design files.f3z]
2026-06-29 added whole assembly STEP via LFS
    [LUME PEN CAD whole assembly.step]
2026-06-29 changing directory of LUME PEN CAD Stencil 3D.step
    [LUME PEN CAD Stencil 3D.step]
